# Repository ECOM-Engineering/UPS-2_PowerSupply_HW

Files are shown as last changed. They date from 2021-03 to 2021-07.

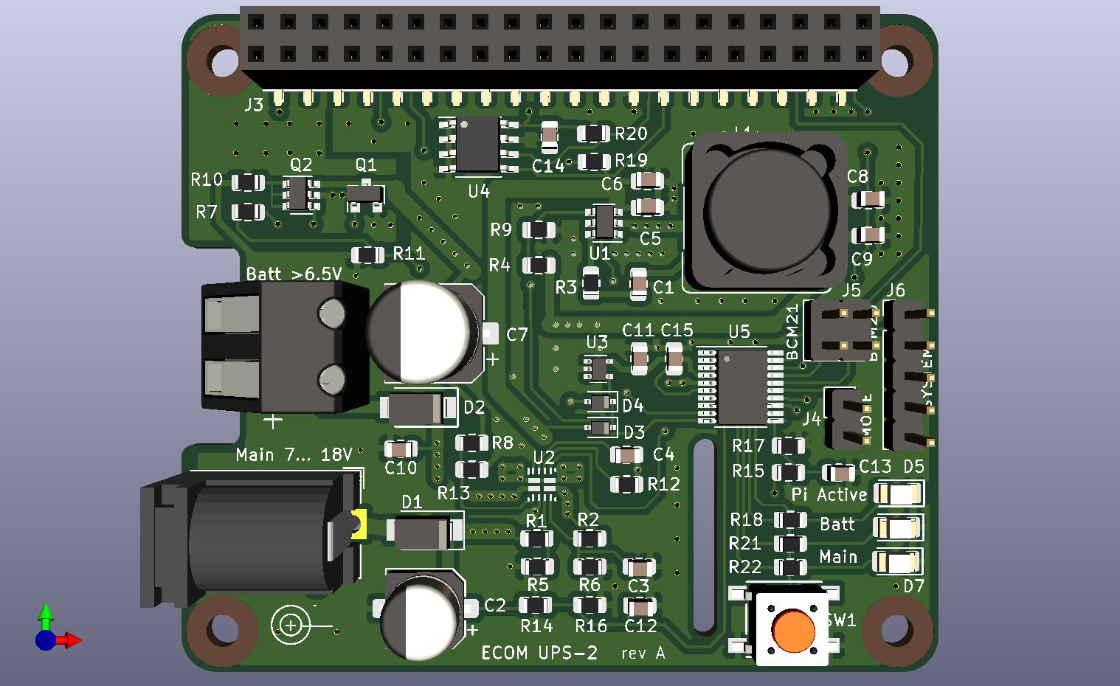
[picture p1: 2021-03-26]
UPS-2.jpg

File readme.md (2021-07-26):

# UPS-2 Power Supply Hardware

***This read me is currently under development***  

This project is the hardware part of the superior **UPS-2** project  
https://github.com/ECOM-Engineering/UPS-2_Uninteruptible-Power-Supply.git .

If you are looking for a simple power-down switch, please refer to the  **s_shut** project  
https://github.com/ECOM-Engineering/Raspberry-Shutdown.git .

## Hardware description

### Summary

**Please refer to the [UPS-2 schematic](./doc/UPS-2 Schematic.pdf).**

UPS-2 hardware builds an uniterruptible, efficient  power supply with a wide input range. There are no glitches during switching and very low power dissipation resulting in cool operation.

Switching between main supply and backup source (usually a battery) is performed by the dedicated [TPS2121](https://www.ti.com/product/TPS2121) switch by TI with no CPU intervention. This guaranties a seamless switchover between the two power inputs. Furthermore, this design allows high efficiency thanks to the very low 56mΩ on resistance. 

5V output voltage regulation is performed by the TI [TPS56339](https://www.ti.com/product/TPS56339) 3A buck converter with an efficieny of >94%. 

Output is protected by the Raspberry standard 'ideal diode' against back driving, if Rasbperry Pi is powered through it's USB connector.

### Input Selector and Power Supply

Please refer to the [TPS2121 data sheet](https://www.ti.com/lit/ds/symlink/tps2121.pdf?ts=1623582270012&ref_url=https%253A%252F%252Fwww.google.com%252F) 

TPS2121 (U2) Power Mux is operated in th 'fast switchover' mode: If input PR1 (derived from Main input) falls below approx. 8V,  U2 switches over to the Battery input without CPU intervention. Capacitors C5, C6, C7 remove switching spikes and Voltage drop during switching over. C7 is a low EMC type with enough capacity in order to limit voltage drop during switching at up to 3A output load.

Voltage scaler allows measuring supply voltages by the ADC of the CPU. In order to minimize quiet current of the voltage sources, it uses as high resistors as possible regarding the input bias of the ADC.

### System Controller

System Controller provides 

- communication with the user via LED indicators and a switch for manual controlling 
- communication with the Raspberry CPU via serial or parallel interface
- firmware flash update via debug port or via Raspberry serial interface

UPS-2 uses an Cortex M0+ CPU of the [STM32G030](https://www.st.com/en/microcontrollers-microprocessors/stm32g030j6.html)  from STMicroelectronics. This CPU provides an incredible 32Bit performance/price ratio. 

### Debug Connector

Debug connetor J6 uses the SWD serial wire debug and flash programming. Pins 1..4 are compatible with the STM32 eval and diccovery boards.

### Hat EEPROM

This memory meets the [Raspberry-Pi Hat specification](https://github.com/raspberrypi/hats) and can be programmed by the user. **Currently, this EEPROM is not used and is unprogrammed.**

### Mode selection

For Jumper Settings and functions please refer to the [UPS-2_User Guide](../UPS-2-Project-repository/UPS-2_Uninteruptible-Power-Supply/doc/user-guide.md)

###  PCB

Board outline corresponds to the mechanical Raspberry-Pi Hat specification.   
UPS-2 uses a 1.6mm 2-layer PCB.

## Used Tools

- [KiCad](https://kicad.org/) EDA system for schematic an PCB layout.
- [Typora](https://typora.io/) for markdown texts (this readme)
- [Libre Office](https://www.libreoffice.org/) for Text and illustrations
- [git](https://git-scm.com/) and [github](https://github.com/)

## Production

This project contains all documents necessary for production including BOM with digikey part numbers and Gerber files for PCB 2-layer production.

In order to make production as simple as possible, PCB uses mostly SMD components that may be produced and soldered by nearly any prototyping service (no fine pitch, 0805 resistors, capacitors). First prototypes have been produced in Switzerland by https://www.quick-pick.ch/. 

## License

**Hardware is licensed under the open source license**  [**CERN-OHLW v2**](https://github.com/ECOM-Engineering/UPS-2_PowerSupply_HW/blob/main/doc/cern_ohl_w_v2.pdf) .

Document Copyright (c) 2021 Klaus Mezger, open source under MIT license.

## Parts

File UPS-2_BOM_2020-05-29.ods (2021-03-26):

 | UPS-2_BOM_2020-05-29 |  |  |  | ECOM ENGINEERING GMBH
ID | Reference | Quantity | Value | Footprint | Digi-Key_PN
1 | C2 | 1 | 47u | Capacitor_SMD:CP_Elec_6.3x5.3 | PCE3908CT-ND
2 | C4 | 1 | 1u | Capacitor_SMD:C_0805_2012Metric | 399-7410-1-ND
3 | C5 C1 C13 C12 C15 C11 C3 C14 | 8 | 100n | Capacitor_SMD:C_0805_2012Metric | 399-1169-1-ND
4 | C6 | 1 | 10u | Capacitor_SMD:C_0805_2012Metric | 445-9015-1-ND
5 | C7 | 1 | 330u/25V | Capacitor_SMD:CP_Elec_8x11.9 | PCE3906CT-ND
6 | C9 C8 C10 | 3 | 22u | Capacitor_SMD:C_0805_2012Metric | 445-14560-1-ND
7 | D2 D1 | 2 | MBRA340 | Diode_SMD:D_SMA | MBRA340T3GOSCT-ND
8 | D4 D3 | 2 | 1N4148WS | Diode_SMD:D_SOD-323 | 1N4148WSTR
9 | D5 | 1 | LED green | LED_SMD:LED_1206_3216Metric | 1516-1073-1-ND
10 | D6 | 1 | LED blue | LED_SMD:LED_1206_3216Metric | 1516-1072-1-ND
11 | D7 | 1 | LED white | LED_SMD:LED_1206_3216Metric | 1516-1074-1-ND
12 | J1 | 1 | PJ-102A | Connector_BarrelJack:BarrelJack_CUI_PJ-102AH_Horizontal | CP-102A-ND
13 | J2 | 1 | Screw_Terminal | TerminalBlock:TerminalBlock_bornier-2_P5.08mm | ED2609-ND
14 | J3 | 1 | OX40HAT | Connector_PinSocket_2.54mm:PinSocket_2x20_P2.54mm_Vertical | 612-HLE-120-02-F-DV-BE-ND
15 | J4 | 1 | Mode | Connector_PinHeader_2.54mm:PinHeader_1x02_P2.54mm_Vertical
16 | J5 | 1 | Ports | Connector_PinHeader_2.54mm:PinHeader_2x02_P2.54mm_Vertical
17 | J6 | 1 | Conn_01x05 | Connector_PinHeader_2.54mm:PinHeader_1x05_P2.54mm_Vertical
18 | L1 | 1 | 5.6uH | Inductor_SMD:L_Bourns_SRR1260 | SRR1260A-5R6YCT-ND
19 | Q1 | 1 | DMG2305UX | Package_TO_SOT_SMD:SOT-23 | DMG2305UX-13DICT-ND
20 | Q2 | 1 | DMMT5401 | Package_TO_SOT_SMD:SOT-23-6 | DMMT5401-FDICT-ND
21 | R11 | 1 | 20k | Resistor_SMD:R_0805_2012Metric
22 | R12 R2 R1 R7 R13 R16 R17 | 7 | 27k | Resistor_SMD:R_0805_2012Metric
23 | R15 R14 | 2 | 220k | Resistor_SMD:R_0805_2012Metric
24 | R22 R18 R21 | 3 | 2.2k | Resistor_SMD:R_0805_2012Metric
25 | R3 | 1 | 30R | Resistor_SMD:R_0805_2012Metric
26 | R4 | 1 | 53.6k | Resistor_SMD:R_0805_2012Metric
27 | R5 | 1 | 1.5k | Resistor_SMD:R_0805_2012Metric
28 | R6 R20 R19 | 3 | 9.1k | Resistor_SMD:R_0805_2012Metric
29 | R8 | 1 | 47k | Resistor_SMD:R_0805_2012Metric
30 | R9 R10 | 2 | 10k | Resistor_SMD:R_0805_2012Metric
31 | SW1 | 1 | 6x6mm | Button_Switch_SMD:SW_SPST_PTS645 | CKN9087DKR-ND
32 | U1 | 1 | TPS56339DDCR | Package_TO_SOT_SMD:SOT-23-6 | 296-53568-1-ND
33 | U2 | 1 | TPS2121 | project_footprints:TPS2121RUXR_V2 | 296-53410-1-ND
34 | U3 | 1 | ST715C33R | Package_TO_SOT_SMD:SOT-353_SC-70-5 | 497-15509-1-ND
35 | U4 | 1 | CAT24C32WI | Package_SO:SO-8_3.9x4.9mm_P1.27mm | CAT24C32WI-GT3CT-ND
36 | U5 | 1 | STM32G030Fx | Package_SO:TSSOP-20_4.4x6.5mm_P0.65mm | STM32G030F6P6
37 | X-J5_1-2 X-J5_2-3 X-J4_1-2 | 3 | Jumper 2.54 |  | S9337-ND

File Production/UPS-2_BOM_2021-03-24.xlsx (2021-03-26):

 | UPS-2_BOM_2021-03-23 |  |  |  | ECOM ENGINEERING
ID | Reference | Quantity | Value | Footprint | Digi-Key_PN
1 | C2 | 1 | 47u | Capacitor_SMD:CP_Elec_6.3x5.3 | PCE3908CT-ND
2 | C4 | 1 | 1u | Capacitor_SMD:C_0805_2012Metric | 399-7410-1-ND
3 | C5 C1 C13 C12 C15 C11 C3 C14 | 8 | 100n | Capacitor_SMD:C_0805_2012Metric | 399-1169-1-ND
4 | C6 | 1 | 10u | Capacitor_SMD:C_0805_2012Metric | 445-9015-1-ND
5 | C7 | 1 | 330u/25V | Capacitor_SMD:CP_Elec_8x11.9 | PCE3906CT-ND
6 | C9 C8 C10 | 3 | 22u | Capacitor_SMD:C_0805_2012Metric | 445-14560-1-ND
7 | D2 D1 | 2 | MBRA340 | Diode_SMD:D_SMA | MBRA340T3GOSCT-ND
8 | D4 D3 | 2 | 1N4148WS | Diode_SMD:D_SOD-323 | 1N4148WSTR
9 | D5 | 1 | LED green | LED_SMD:LED_1206_3216Metric | 1516-1073-1-ND
10 | D6 | 1 | LED blue | LED_SMD:LED_1206_3216Metric | 1516-1072-1-ND
11 | D7 | 1 | LED white | LED_SMD:LED_1206_3216Metric | 1516-1074-1-ND
12 | J1 | 1 | PJ-102A | Connector_BarrelJack:BarrelJack_CUI_PJ-102AH_Horizontal | CP-102A-ND
13 | J2 | 1 | Screw_Terminal | TerminalBlock:TerminalBlock_bornier-2_P5.08mm | ED2609-ND
14 | J3 | 1 | OX40HAT | Connector_PinSocket_2.54mm:PinSocket_2x20_P2.54mm_Vertical | 612-HLE-120-02-F-DV-BE-ND
15 | J4 | 1 | Mode | Connector_PinHeader_2.54mm:PinHeader_1x02_P2.54mm_Vertical
16 | J5 | 1 | Ports | Connector_PinHeader_2.54mm:PinHeader_2x02_P2.54mm_Vertical
17 | J6 | 1 | Conn_01x05 | Connector_PinHeader_2.54mm:PinHeader_1x05_P2.54mm_Vertical
18 | L1 | 1 | 5.6uH | Inductor_SMD:L_Bourns_SRR1260 | SRR1260A-5R6YCT-ND
19 | Q1 | 1 | DMG2305UX | Package_TO_SOT_SMD:SOT-23 | DMG2305UX-13DICT-ND
20 | Q2 | 1 | DMMT5401 | Package_TO_SOT_SMD:SOT-23-6 | DMMT5401-FDICT-ND
21 | R11 | 1 | 20k | Resistor_SMD:R_0805_2012Metric
22 | R12 R2 R1 R7 R13 R16 | 6 | 27k | Resistor_SMD:R_0805_2012Metric
23 | R14 | 1 | 220k | Resistor_SMD:R_0805_2012Metric
24 | R15 | 1 | 510k | Resistor_SMD:R_0805_2012Metric
25 | R17 | 1 | 62k | Resistor_SMD:R_0805_2012Metric
26 | R22 R18 R21 | 3 | 2.2k | Resistor_SMD:R_0805_2012Metric
27 | R3 | 1 | 30R | Resistor_SMD:R_0805_2012Metric
28 | R4 | 1 | 53.6k | Resistor_SMD:R_0805_2012Metric
29 | R5 | 1 | 1.5k | Resistor_SMD:R_0805_2012Metric
30 | R6 R20 R19 | 3 | 9.1k | Resistor_SMD:R_0805_2012Metric
31 | R8 | 1 | 47k | Resistor_SMD:R_0805_2012Metric
32 | R9 R10 | 2 | 10k | Resistor_SMD:R_0805_2012Metric
33 | SW1 | 1 | 6x6mm | Button_Switch_SMD:SW_SPST_PTS645 | CKN9087DKR-ND
34 | U1 | 1 | TPS56339DDCR | Package_TO_SOT_SMD:SOT-23-6 | 296-53568-1-ND
35 | U2 | 1 | TPS2121 | project_footprints:TPS2121RUXR_V2 | 296-53410-1-ND
36 | U3 | 1 | ST715C33R | Package_TO_SOT_SMD:SOT-353_SC-70-5 | 497-15509-1-ND
37 | U4 | 1 | CAT24C32WI | Package_SO:SO-8_3.9x4.9mm_P1.27mm | CAT24C32WI-GT3CT-ND
38 | U5 | 1 | STM32G030Fx | Package_SO:TSSOP-20_4.4x6.5mm_P0.65mm | STM32G030F6P6
39 | X-J5_1-2 X-J5_2-3 X-J4_1-2 | 3 | Jumper 2.54 |  | S9337-ND
 | Off board:
40 | J3 + |  | Header 2x40 | 40 pin Stacking Header | 1528-1783-ND
40a | J3 + alternative |  |  | Adafruit 2x20 Extra tall header ID 1979 | xxx

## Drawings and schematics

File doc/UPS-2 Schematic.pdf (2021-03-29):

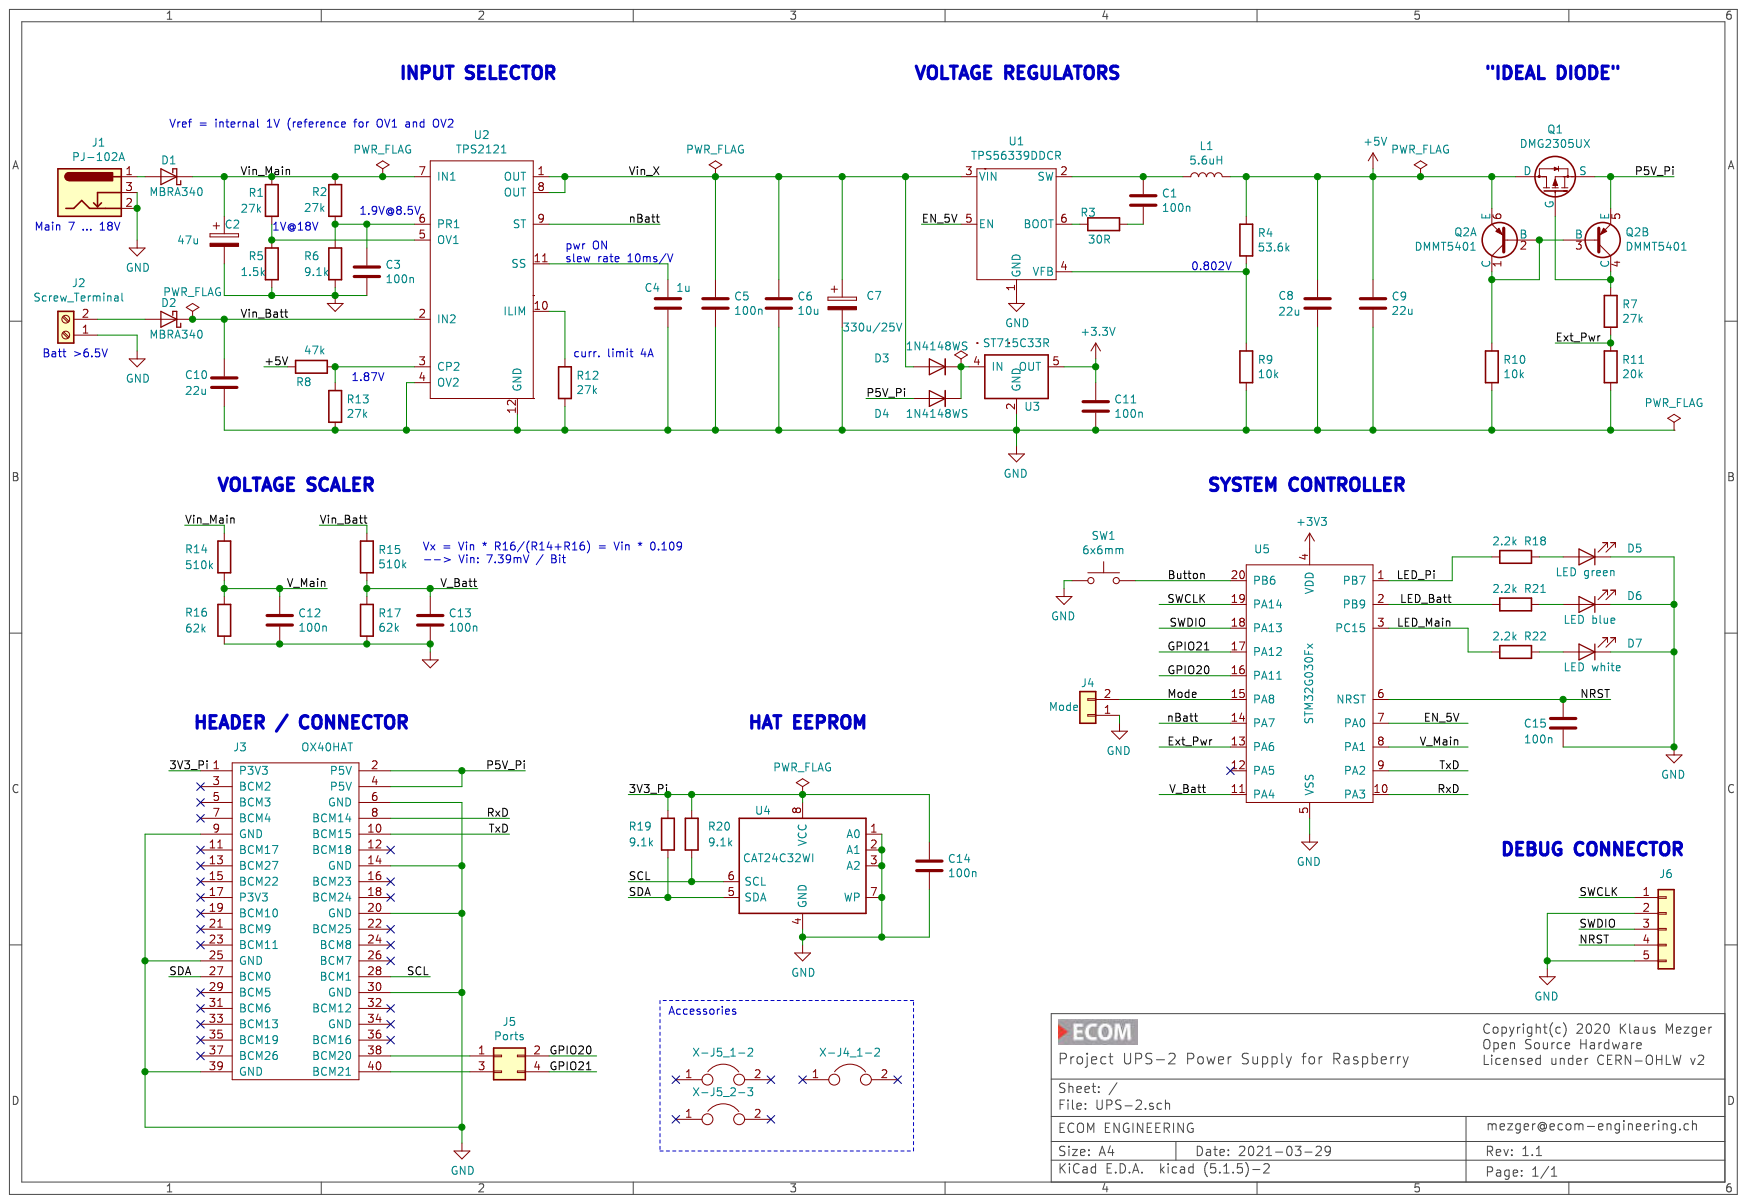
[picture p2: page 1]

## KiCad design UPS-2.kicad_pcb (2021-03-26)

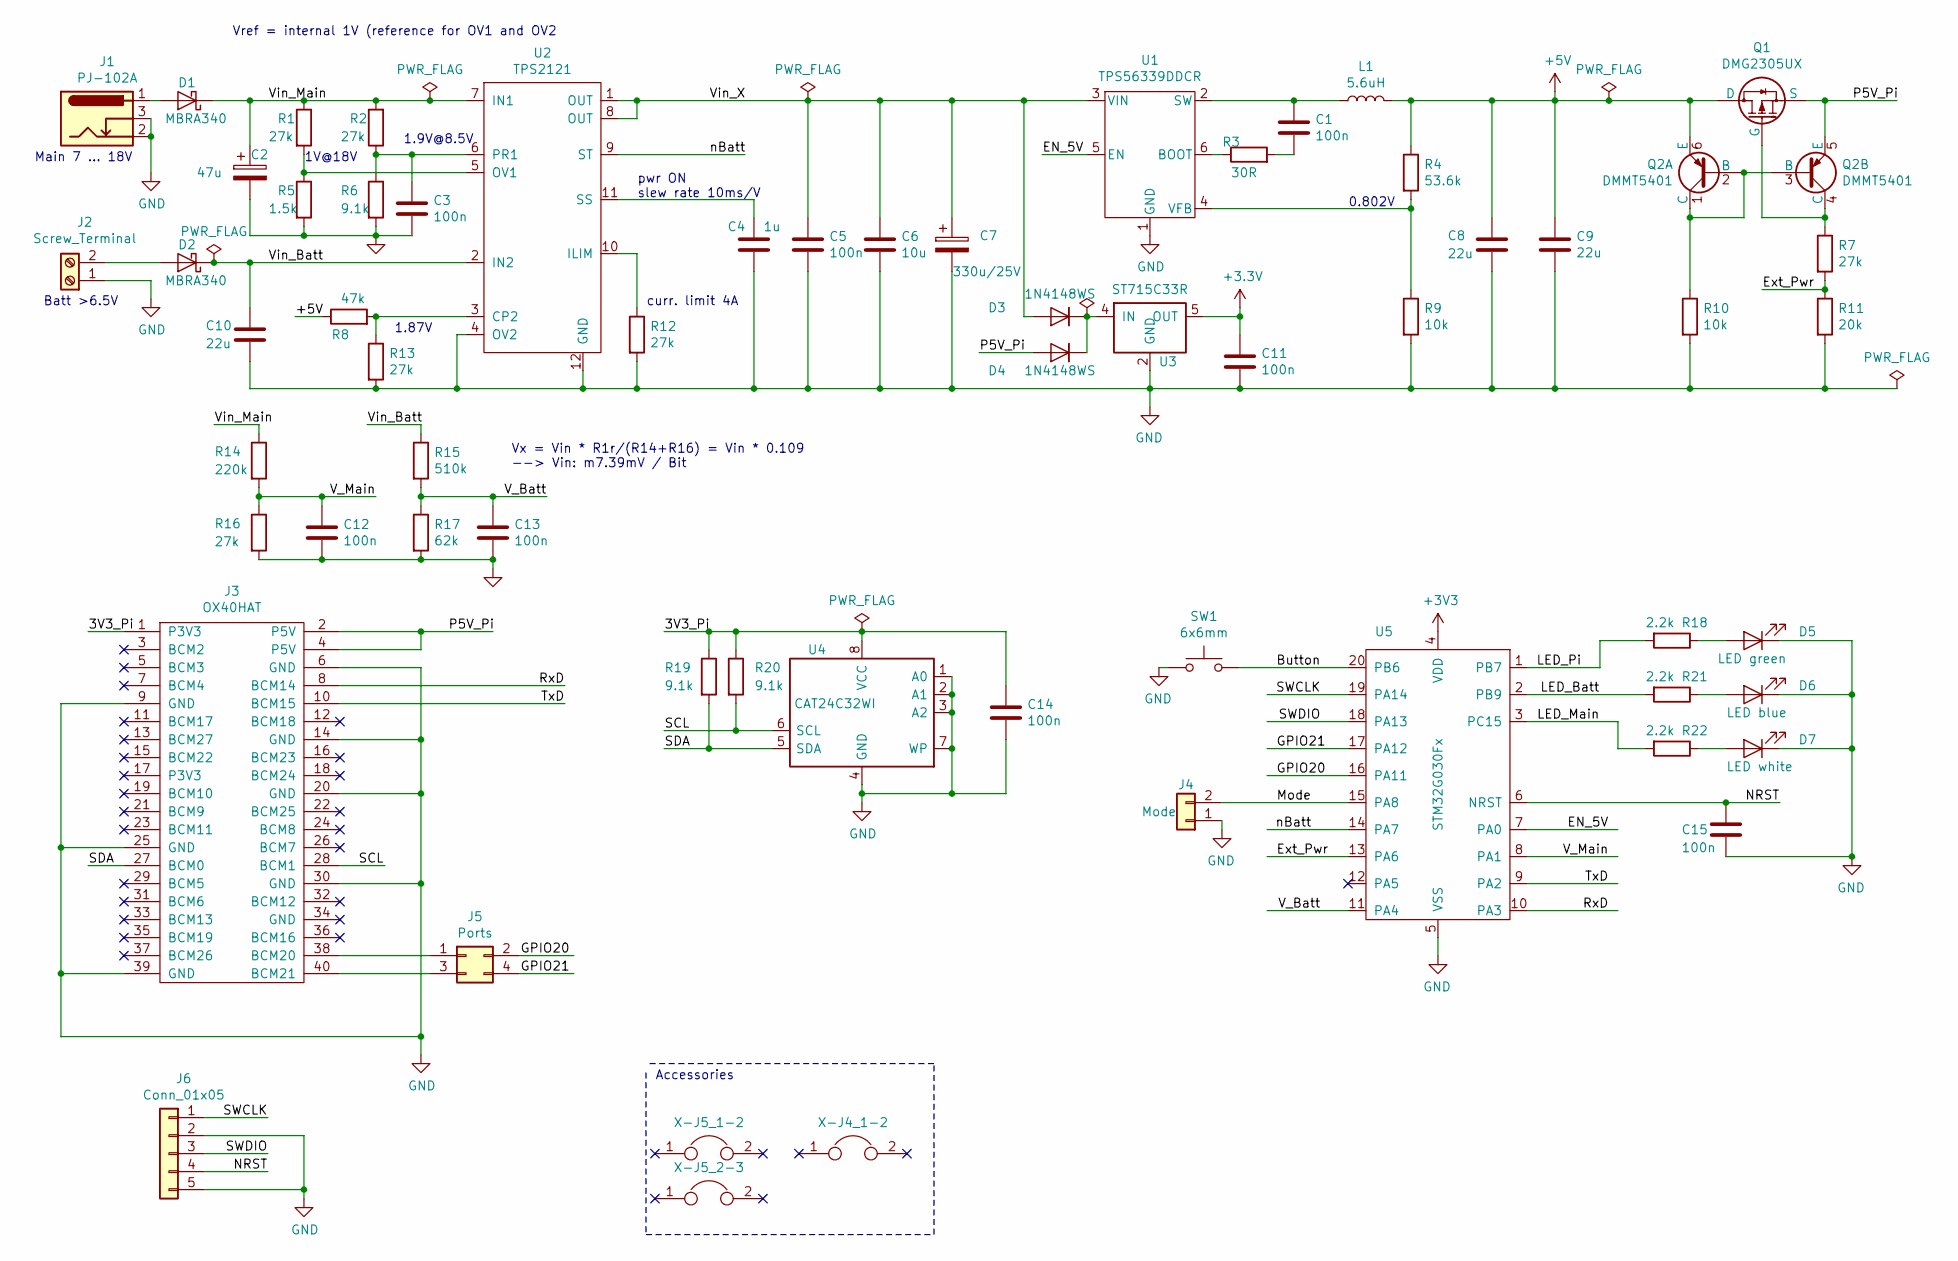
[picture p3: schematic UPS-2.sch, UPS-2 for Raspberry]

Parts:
C1, C3, C11, C12, C13, C14, C15: 100n; C_0805_2012Metric
C2: 47u; CP_Elec_6.3x5.3; Digi-Key_PN PCE3908CT-ND
C4: 1u; C_0805_2012Metric; Digi-Key_PN 399-7410-1-ND
C5: 100n; C_0805_2012Metric; Digi-Key_PN 399-1169-1-ND
C6: 10u; C_0805_2012Metric; Digi-Key_PN 445-9015-1-ND
C7: 330u/25V; CP_Elec_8x11.9; Digi-Key_PN PCE3906CT-ND
C8, C9: 22u; C_0805_2012Metric; Digi-Key_PN 445-14560-1-ND
C10: 22u; C_0805_2012Metric
D1, D2: MBRA340; D_SMA; Digi-Key_PN MBRA340T3GOSCT-ND
D3, D4: 1N4148WS; D_SOD-323; Digi-Key_PN 1N4148WSTR
D5: LED green; LED_1206_3216Metric; Digi-Key_PN 1516-1073-1-ND
D6: LED blue; LED_1206_3216Metric; Digi-Key_PN 1516-1072-1-ND
D7: LED white; LED_1206_3216Metric; Digi-Key_PN 1516-1074-1-ND
J1: PJ-102A; BarrelJack_CUI_PJ-102AH_Horizontal; Digi-Key_PN CP-102A-ND
J2: Screw_Terminal; TerminalBlock_bornier-2_P5.08mm; Digi-Key_PN ED2609-ND
J3: OX40HAT; PinSocket_2x20_P2.54mm_Vertical; Digi-Key_PN 612-HLE-120-02-F-DV-BE-ND
J4: Mode; PinHeader_1x02_P2.54mm_Vertical
J5: Ports; PinHeader_2x02_P2.54mm_Vertical
J6: Conn_01x05; PinHeader_1x05_P2.54mm_Vertical
L1: 5.6uH; L_Bourns_SRR1260; Digi-Key_PN SRR1260A-5R6YCT-ND
Q1: DMG2305UX; SOT-23; Digi-Key_PN DMG2305UX-13DICT-ND
Q2: DMMT5401; SOT-23-6; Digi-Key_PN DMMT5401-FDICT-ND
R1, R2, R7, R12, R13, R16: 27k; R_0805_2012Metric
R3: 30R; R_0805_2012Metric
R4: 53.6k; R_0805_2012Metric
R5: 1.5k; R_0805_2012Metric
R6, R19, R20: 9.1k; R_0805_2012Metric
R8: 47k; R_0805_2012Metric
R9, R10: 10k; R_0805_2012Metric
R11: 20k; R_0805_2012Metric
R14: 220k; R_0805_2012Metric
R15: 510k; R_0805_2012Metric
R17: 62k; R_0805_2012Metric
R18, R21, R22: 2.2k; R_0805_2012Metric
SW1: 6x6mm; SW_SPST_PTS645; Digi-Key_PN CKN9087DKR-ND
U1: TPS56339DDCR; SOT-23-6; Digi-Key_PN 296-53568-1-ND
U2: TPS2121; TPS2121RUXR_V2; Digi-Key_PN 296-53410-1-ND
U3: ST715C33R; SOT-353_SC-70-5; Digi-Key_PN 497-15509-1-ND
U4: CAT24C32WI; SO-8_3.9x4.9mm_P1.27mm; Digi-Key_PN CAT24C32WI-GT3CT-ND
U5: STM32G030Fx; TSSOP-20_4.4x6.5mm_P0.65mm; Digi-Key_PN STM32G030F6P6
X-J4_1-2, X-J5_1-2, X-J5_2-3: Jumper 2.54; Digi-Key_PN S9337-ND

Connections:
+5V: C8.1, C9.1, L1.2, Q1.3 (D), Q2.6 (E), R4.1, R8.1
/3V3_Pi: C14.1, J3.1 (P3V3), R19.1, R20.1, U4.8 (VCC)
/Button: SW1.1, U5.20 (PB6)
/EN_5V: U1.5 (EN), U5.7 (PA0)
/Ext_Pwr: R7.2, R11.1, U5.13 (PA6)
/GPIO20: J5.2, U5.16 (PA11)
/GPIO21: J5.4, U5.17 (PA12)
/LED_Batt: R21.2, U5.2 (PB9)
/LED_Main: R22.2, U5.3 (PC15)
/LED_Pi: R18.2, U5.1 (PB7)
/Mode: J4.2, U5.15 (PA8)
/NRST: C15.1, J6.4, U5.6 (NRST)
/P5V_Pi: D4.2 (A), J3.2 (P5V), J3.4 (P5V), Q1.2 (S), Q2.5 (E)
/RxD: J3.8 (BCM14), U5.10 (PA3)
/SCL: J3.28 (BCM1), R20.2, U4.6 (SCL)
/SDA: J3.27 (BCM0), R19.2, U4.5 (SDA)
/SWCLK: J6.1, U5.19 (PA14)
/SWDIO: J6.3, U5.18 (PA13)
/TxD: J3.10 (BCM15), U5.9 (PA2)
/V_Batt: C13.1, R15.2, R17.1, U5.11 (PA4)
/V_Main: C12.1, R14.2, R16.1, U5.8 (PA1)
/Vin_Batt: C10.1, D2.1 (K), R15.1, U2.2 (IN2)
/Vin_Main: C2.1, D1.1 (K), R1.1, R2.2, R14.1, U2.7 (IN1)
/Vin_X: C5.1, C6.1, C7.1, D3.2 (A), U1.3 (VIN), U2.1 (OUT), U2.8 (OUT)
/nBatt: U2.9 (ST), U5.14 (PA7)
GND: C2.2, C3.2, C4.2, C5.2, C6.2, C7.2, C8.2, C9.2, C10.2, C11.2, C12.2, C13.2, C14.2, C15.2, D5.1 (K), D6.1 (K), D7.1 (K), J1.2, J1.3, J2.1, J3.6 (GND), J3.9 (GND), J3.14 (GND), J3.20 (GND), J3.25 (GND), J3.30 (GND), J3.39 (GND), J4.1, J6.2, J6.5, R5.2, R6.2, R9.2, R10.2, R11.2, R12.2, R13.2, R16.2, R17.2, SW1.2, U1.1 (GND), U2.4 (OV2), U2.12 (GND), U3.2 (GND), U4.1 (A0), U4.2 (A1), U4.3 (A2), U4.4 (GND), U4.7 (WP), U5.5 (VSS)
unnamed: C1.1, L1.1, U1.2 (SW)
unnamed: C1.2, R3.2
unnamed: C3.1, R2.1, R6.1, U2.6 (PR1)
unnamed: C4.1, U2.11 (SS)
unnamed: D1.2 (A), J1.1
unnamed: D2.2 (A), J2.2
unnamed: D3.1 (K), D4.1 (K), U3.4 (IN)
unnamed: D5.2 (A), R18.1
unnamed: D6.2 (A), R21.1
unnamed: D7.2 (A), R22.1
unnamed: J3.38 (BCM20), J5.1
unnamed: J3.40 (BCM21), J5.3
unnamed: Q1.1 (G), Q2.4 (C), R7.1
unnamed: Q2.1 (C), Q2.2 (B), Q2.3 (B), R10.1
unnamed: R1.2, R5.1, U2.5 (OV1)
unnamed: R3.1, U1.6 (BOOT)
unnamed: R4.2, R9.1, U1.4 (VFB)
unnamed: R12.1, U2.10 (ILIM)
unnamed: R8.2, R13.1, U2.3 (CP2)

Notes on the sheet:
pwr ON slew rate 10ms/V
curr. limit 4A
1.87V
1.9V@8.5V
1V@18V
Vref = internal 1V (reference for OV1 and OV2
0.802V
Accessories
Vx = Vin * R1r/(R14+R16) = Vin * 0.109 --> Vin: m7.39mV / Bit
Batt >6.5V
Main 7 ... 18V

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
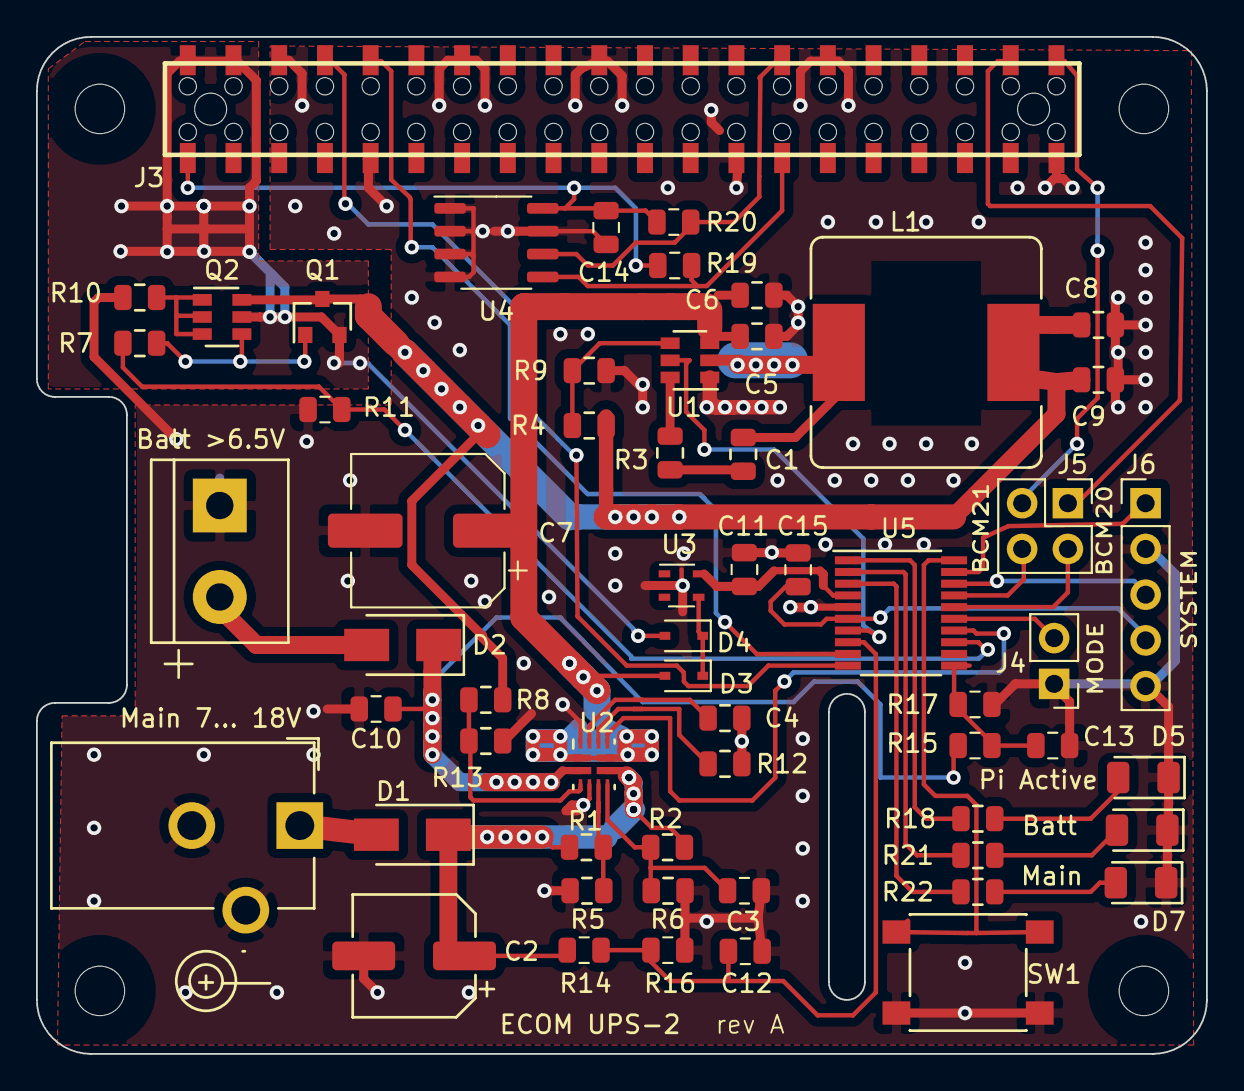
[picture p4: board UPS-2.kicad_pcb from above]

Board: 2 copper layers, 65.0 x 56.5 mm, 59 parts (0 on the bottom side), 46 nets.

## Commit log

2021-03-26 File VoltageDevider removed
2021-03-29 readme + schematic update
    [UPS-2-Kopie-x.sch, UPS-2.sch]
2021-03-29 readme and schematic PDF added

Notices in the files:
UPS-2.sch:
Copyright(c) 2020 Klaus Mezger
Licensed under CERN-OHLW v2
